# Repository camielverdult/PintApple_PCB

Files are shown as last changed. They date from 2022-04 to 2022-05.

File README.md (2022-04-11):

# PintApple PCB

This is version 2 of the PCB made for Project Integration in Applied Computer Science year 2 at Saxion Enschede.

## Features

| Function | Main part | Comments |
|---|---|---|
| MCU | [ESP32-S2-WROVER](https://www.espressif.com/sites/default/files/documentation/esp32-s2-wroom_esp32-s2-wroom-i_datasheet_en.pdf) | |
| Power | [XC6222B331MR-G](https://www.farnell.com/datasheets/3118383.pdf) | 3.3V, 700mA |
| Accelerometer | [MMA8652FCR1](https://www.farnell.com/datasheets/1869253.pdf) | |
| Display | [SSD1306 OLED](https://cdn-shop.adafruit.com/datasheets/SSD1306.pdf) | |
| Microphone | [MAX9814](https://www.adafruit.com/product/1713) | |
| SD card | [472192001](https://www.molex.com/molex/products/part-detail/memory_card_socket/0472192001) | |
| Heartbeat | [MAX30102](http://www.arduinoproducts.net/products/mh-et-live-max30102-heart-rate-sensor-module-puls-detection-blood-oxygen-concentration-test-for-arduino-ultra-low-power/) | |

## Renders

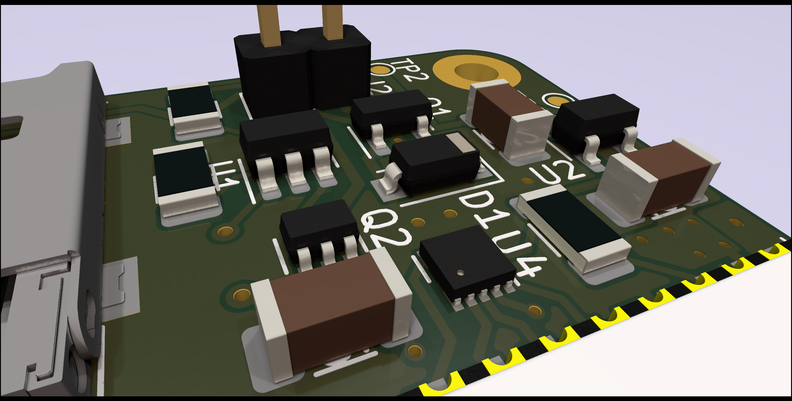
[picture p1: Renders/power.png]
Power circuitry


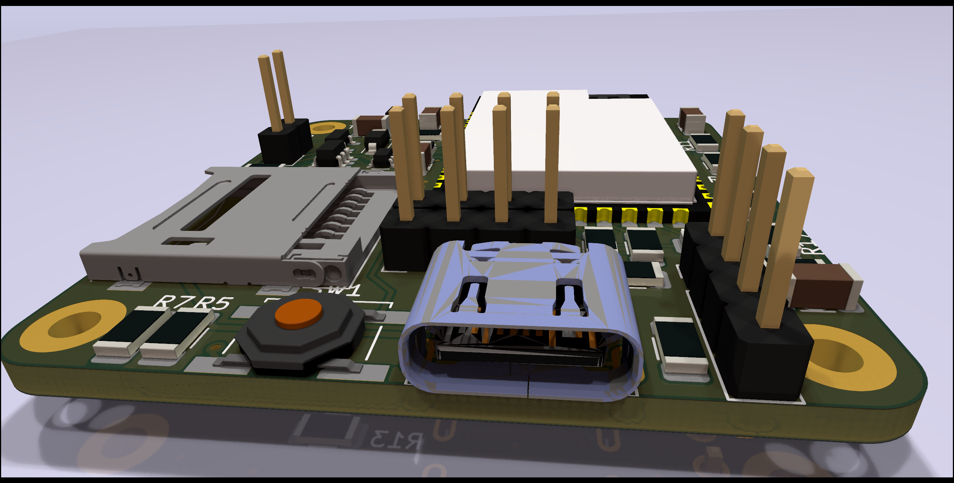
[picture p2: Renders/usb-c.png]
USB-C port


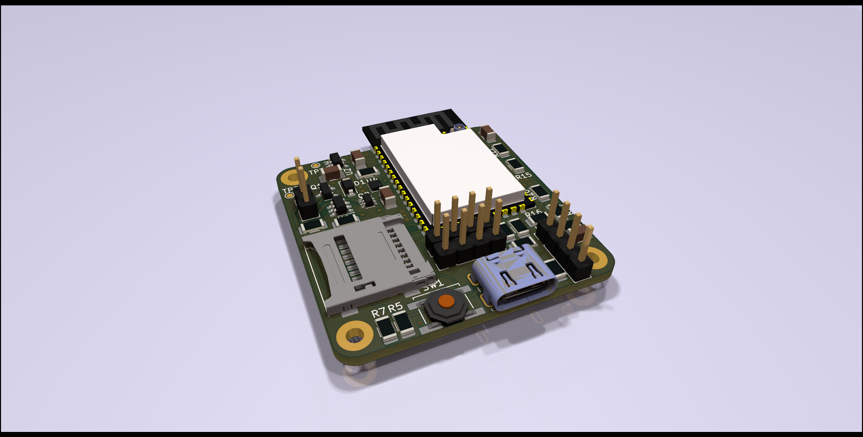
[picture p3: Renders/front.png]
Front side


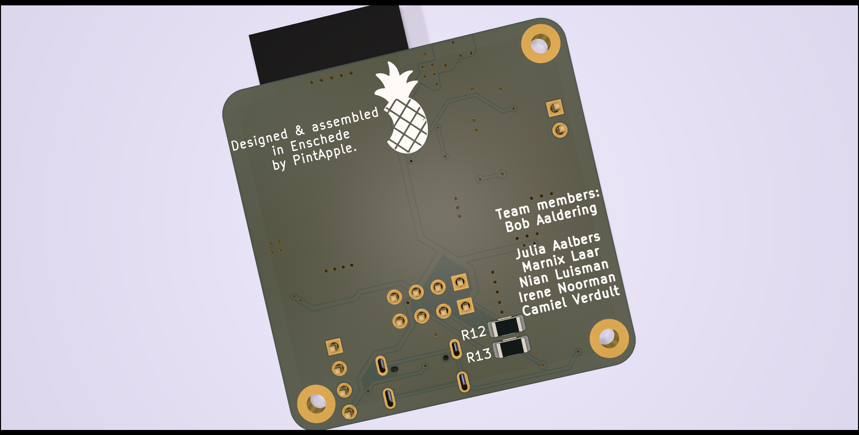
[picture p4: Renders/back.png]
Back side


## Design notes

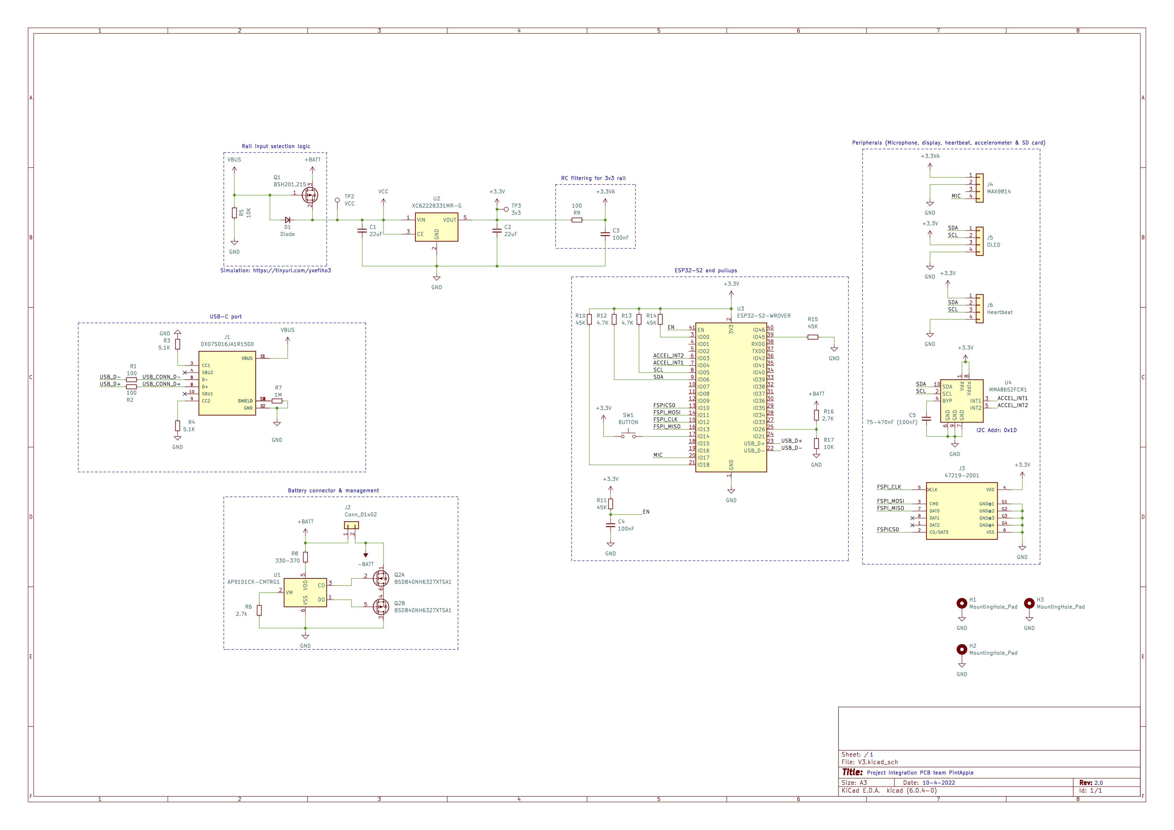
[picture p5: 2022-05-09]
Schematics/schematic_transparent.png

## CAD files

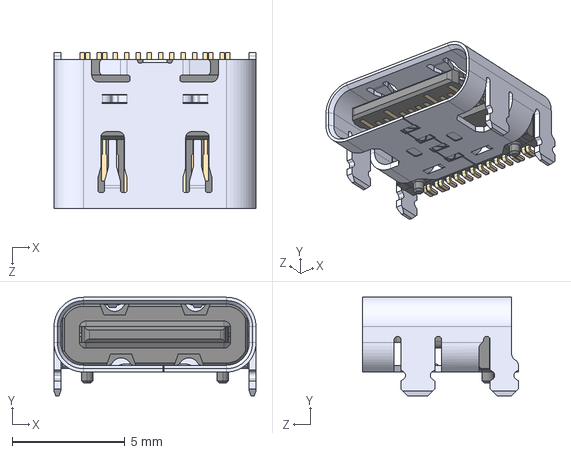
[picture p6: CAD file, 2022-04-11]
Project_3dmodels/DX07S016JA1R1500.STEP
8.94 x 4.36 x 6.90 mm

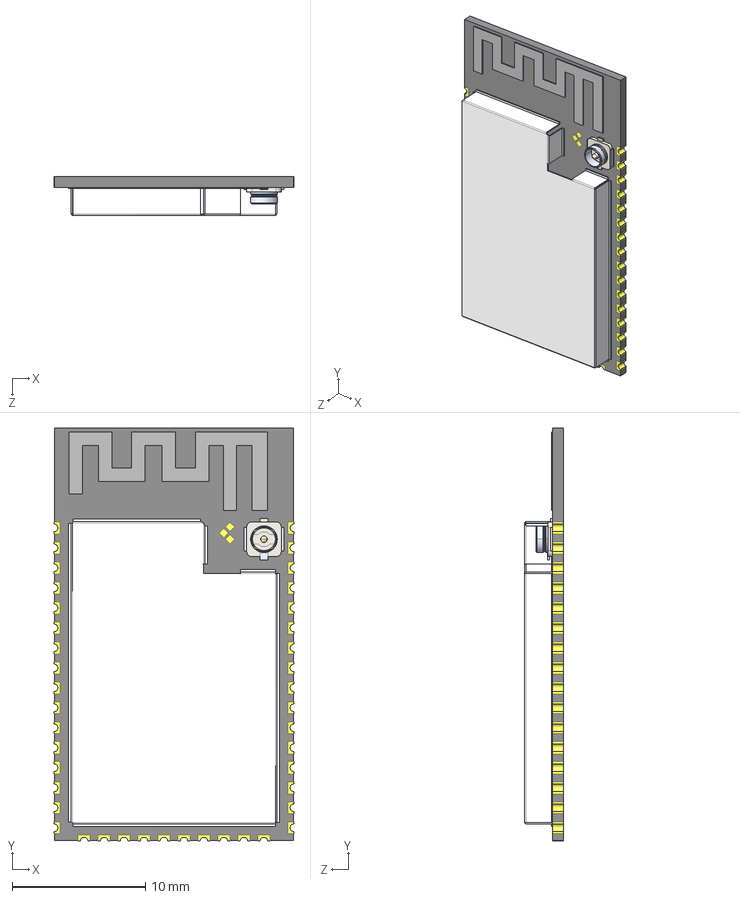
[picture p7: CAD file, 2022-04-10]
Project_3dmodels/ESP32-S2-WROVER.STEP
18.0 x 31.0 x 2.91 mm

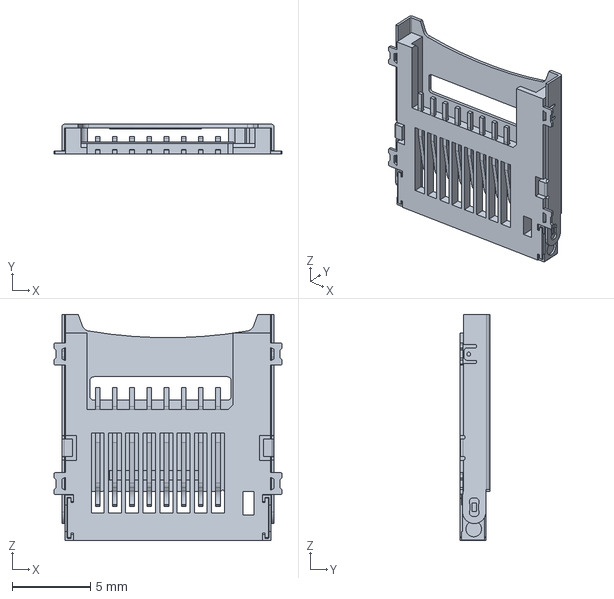
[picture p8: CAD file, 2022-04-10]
Project_3dmodels/472192001.stp
14.6 x 1.90 x 14.5 mm

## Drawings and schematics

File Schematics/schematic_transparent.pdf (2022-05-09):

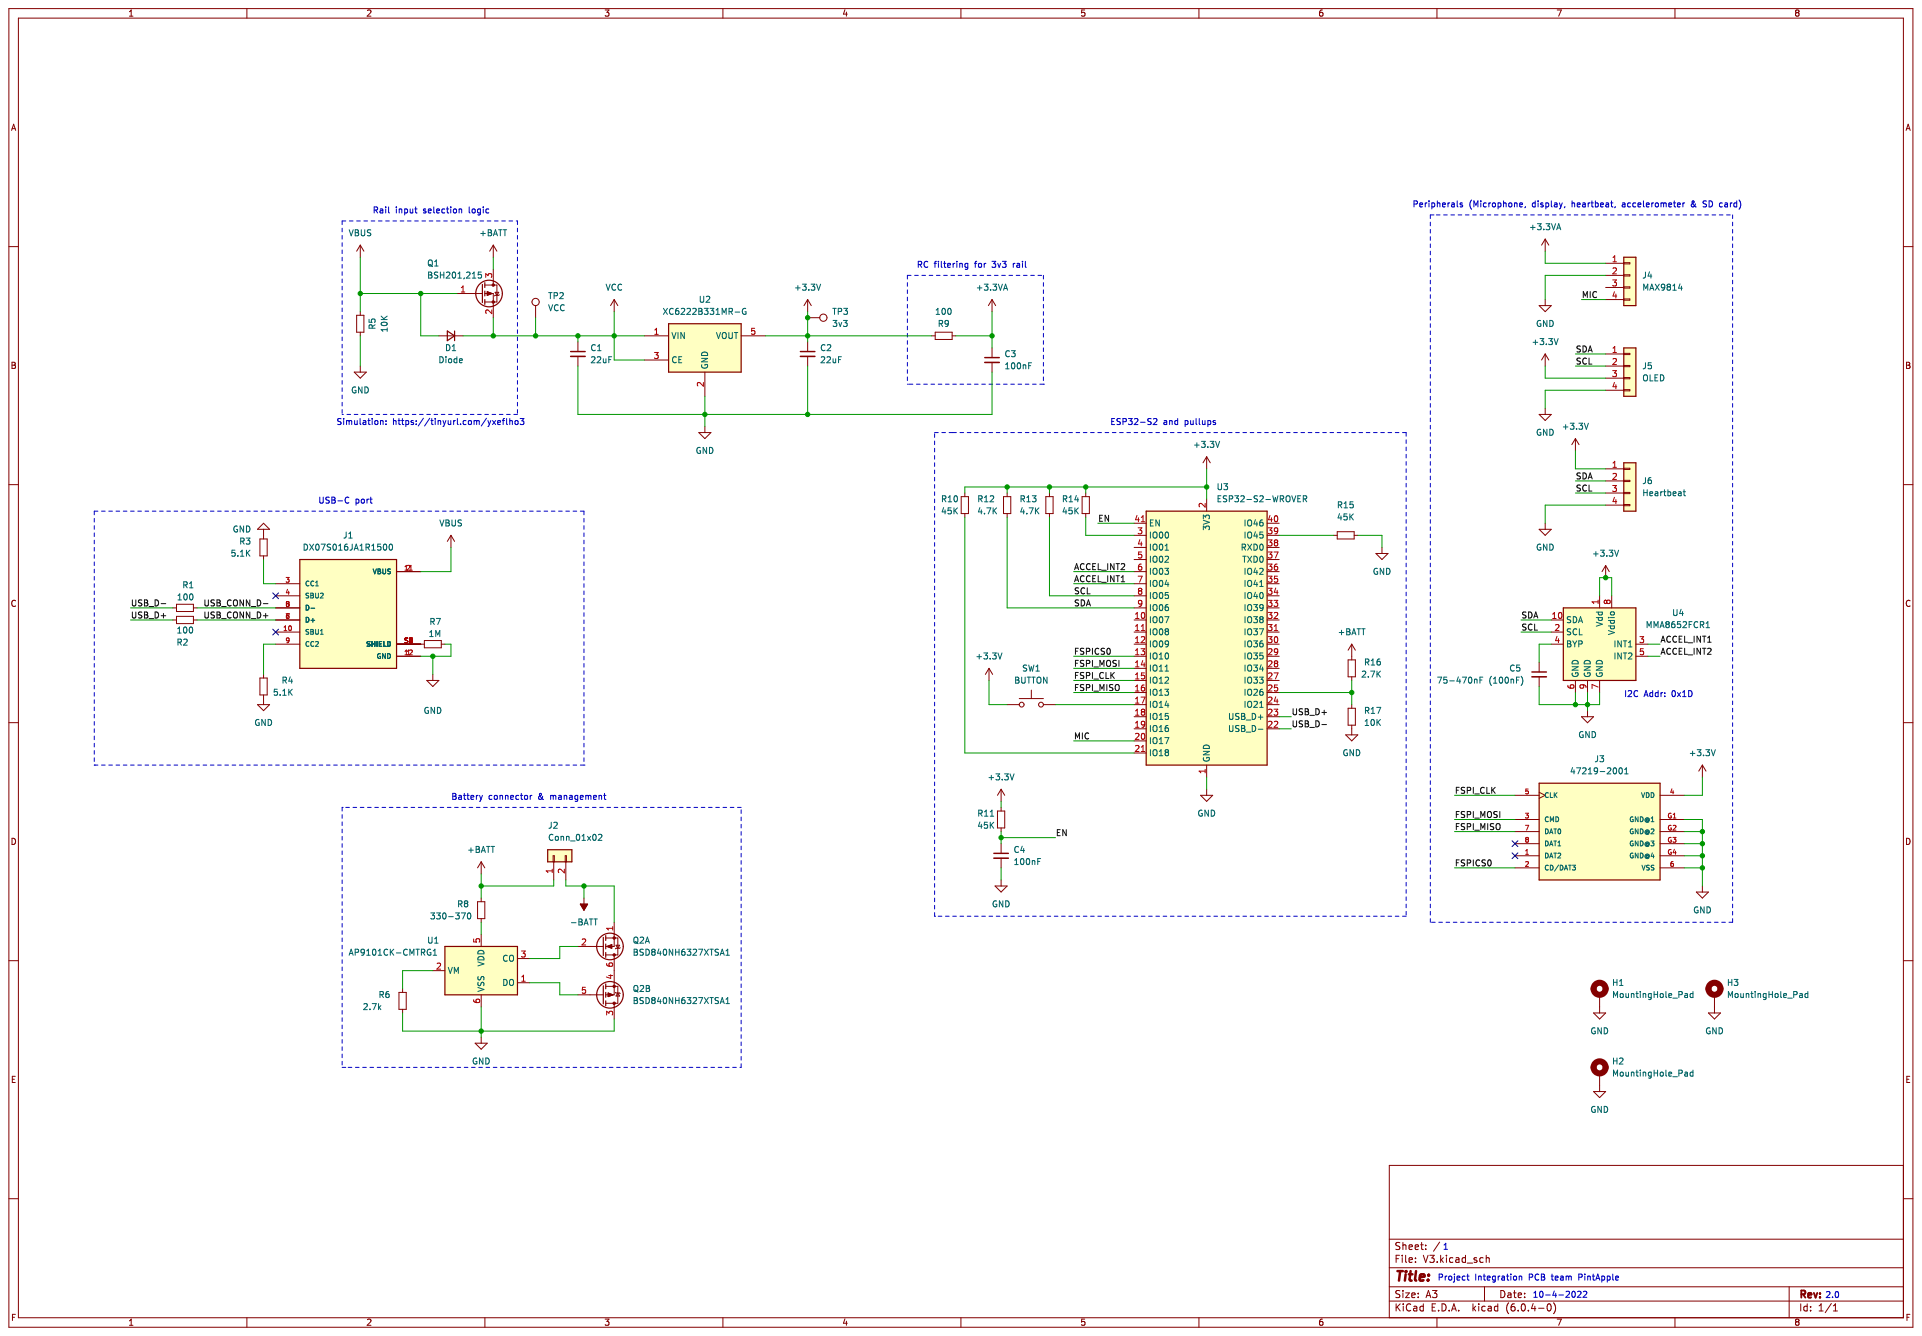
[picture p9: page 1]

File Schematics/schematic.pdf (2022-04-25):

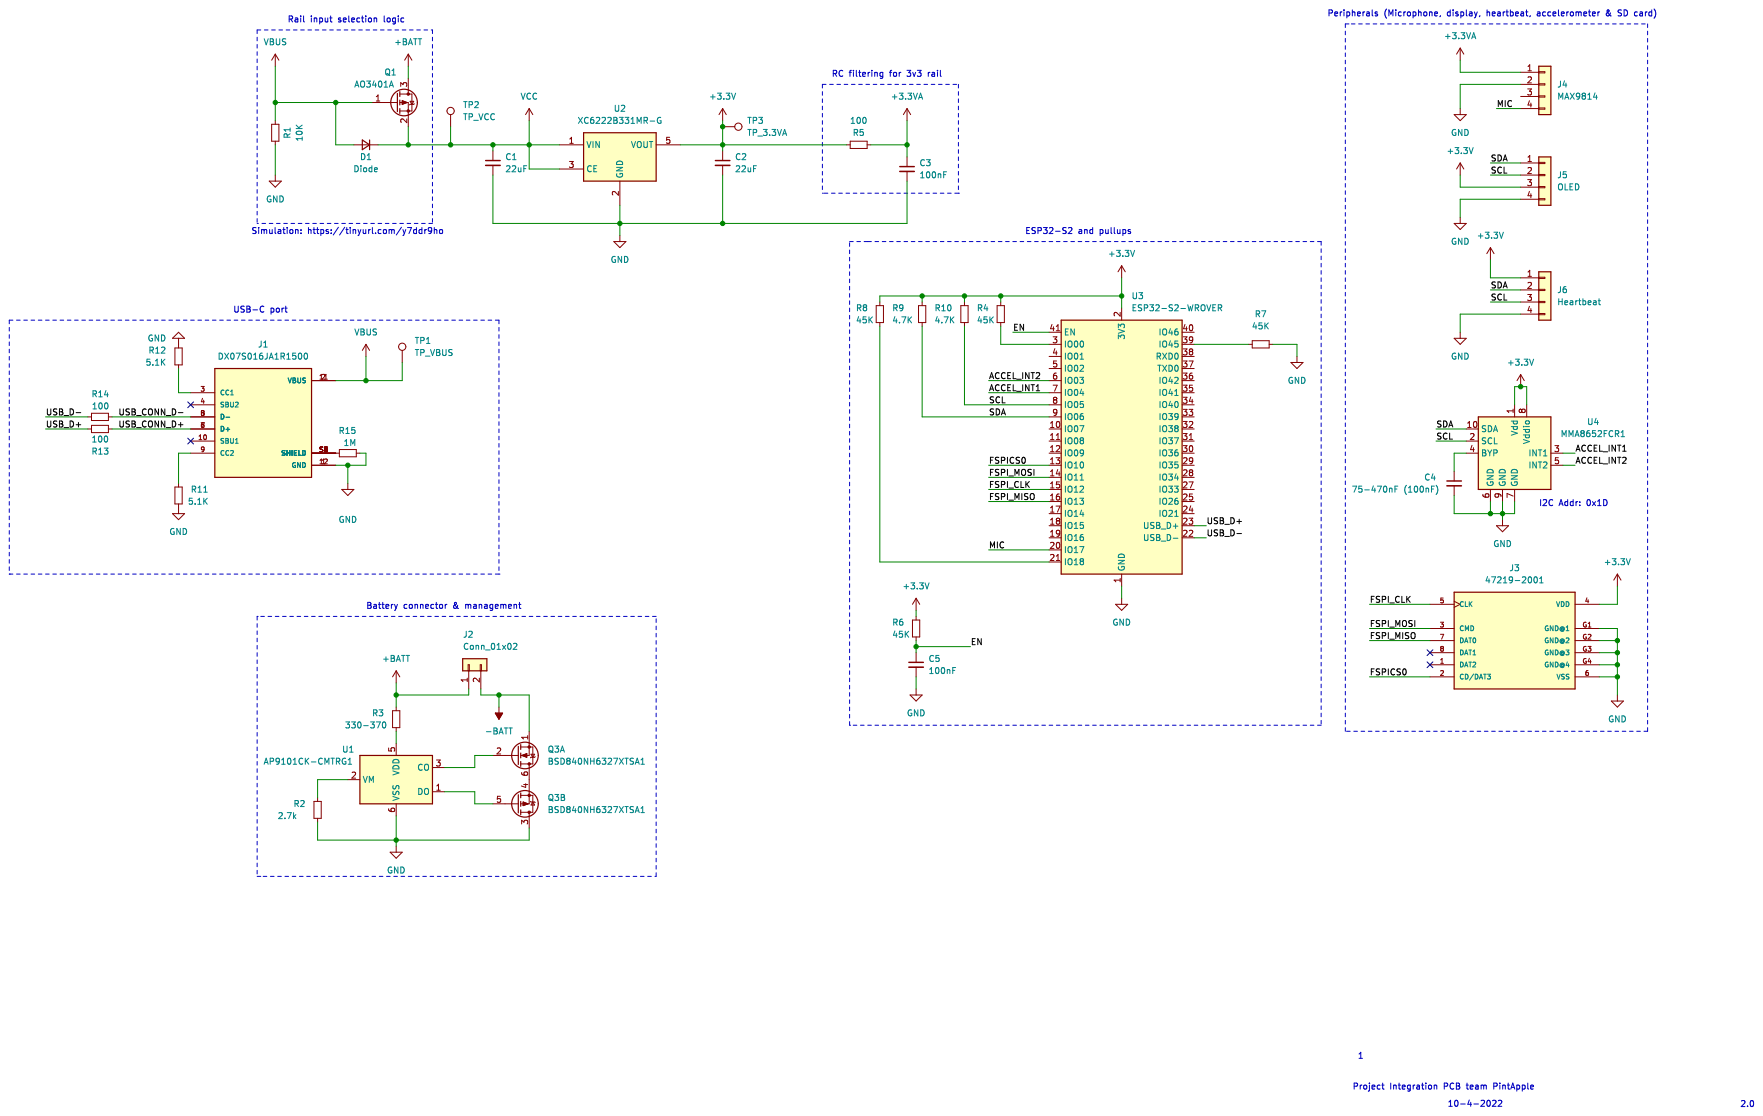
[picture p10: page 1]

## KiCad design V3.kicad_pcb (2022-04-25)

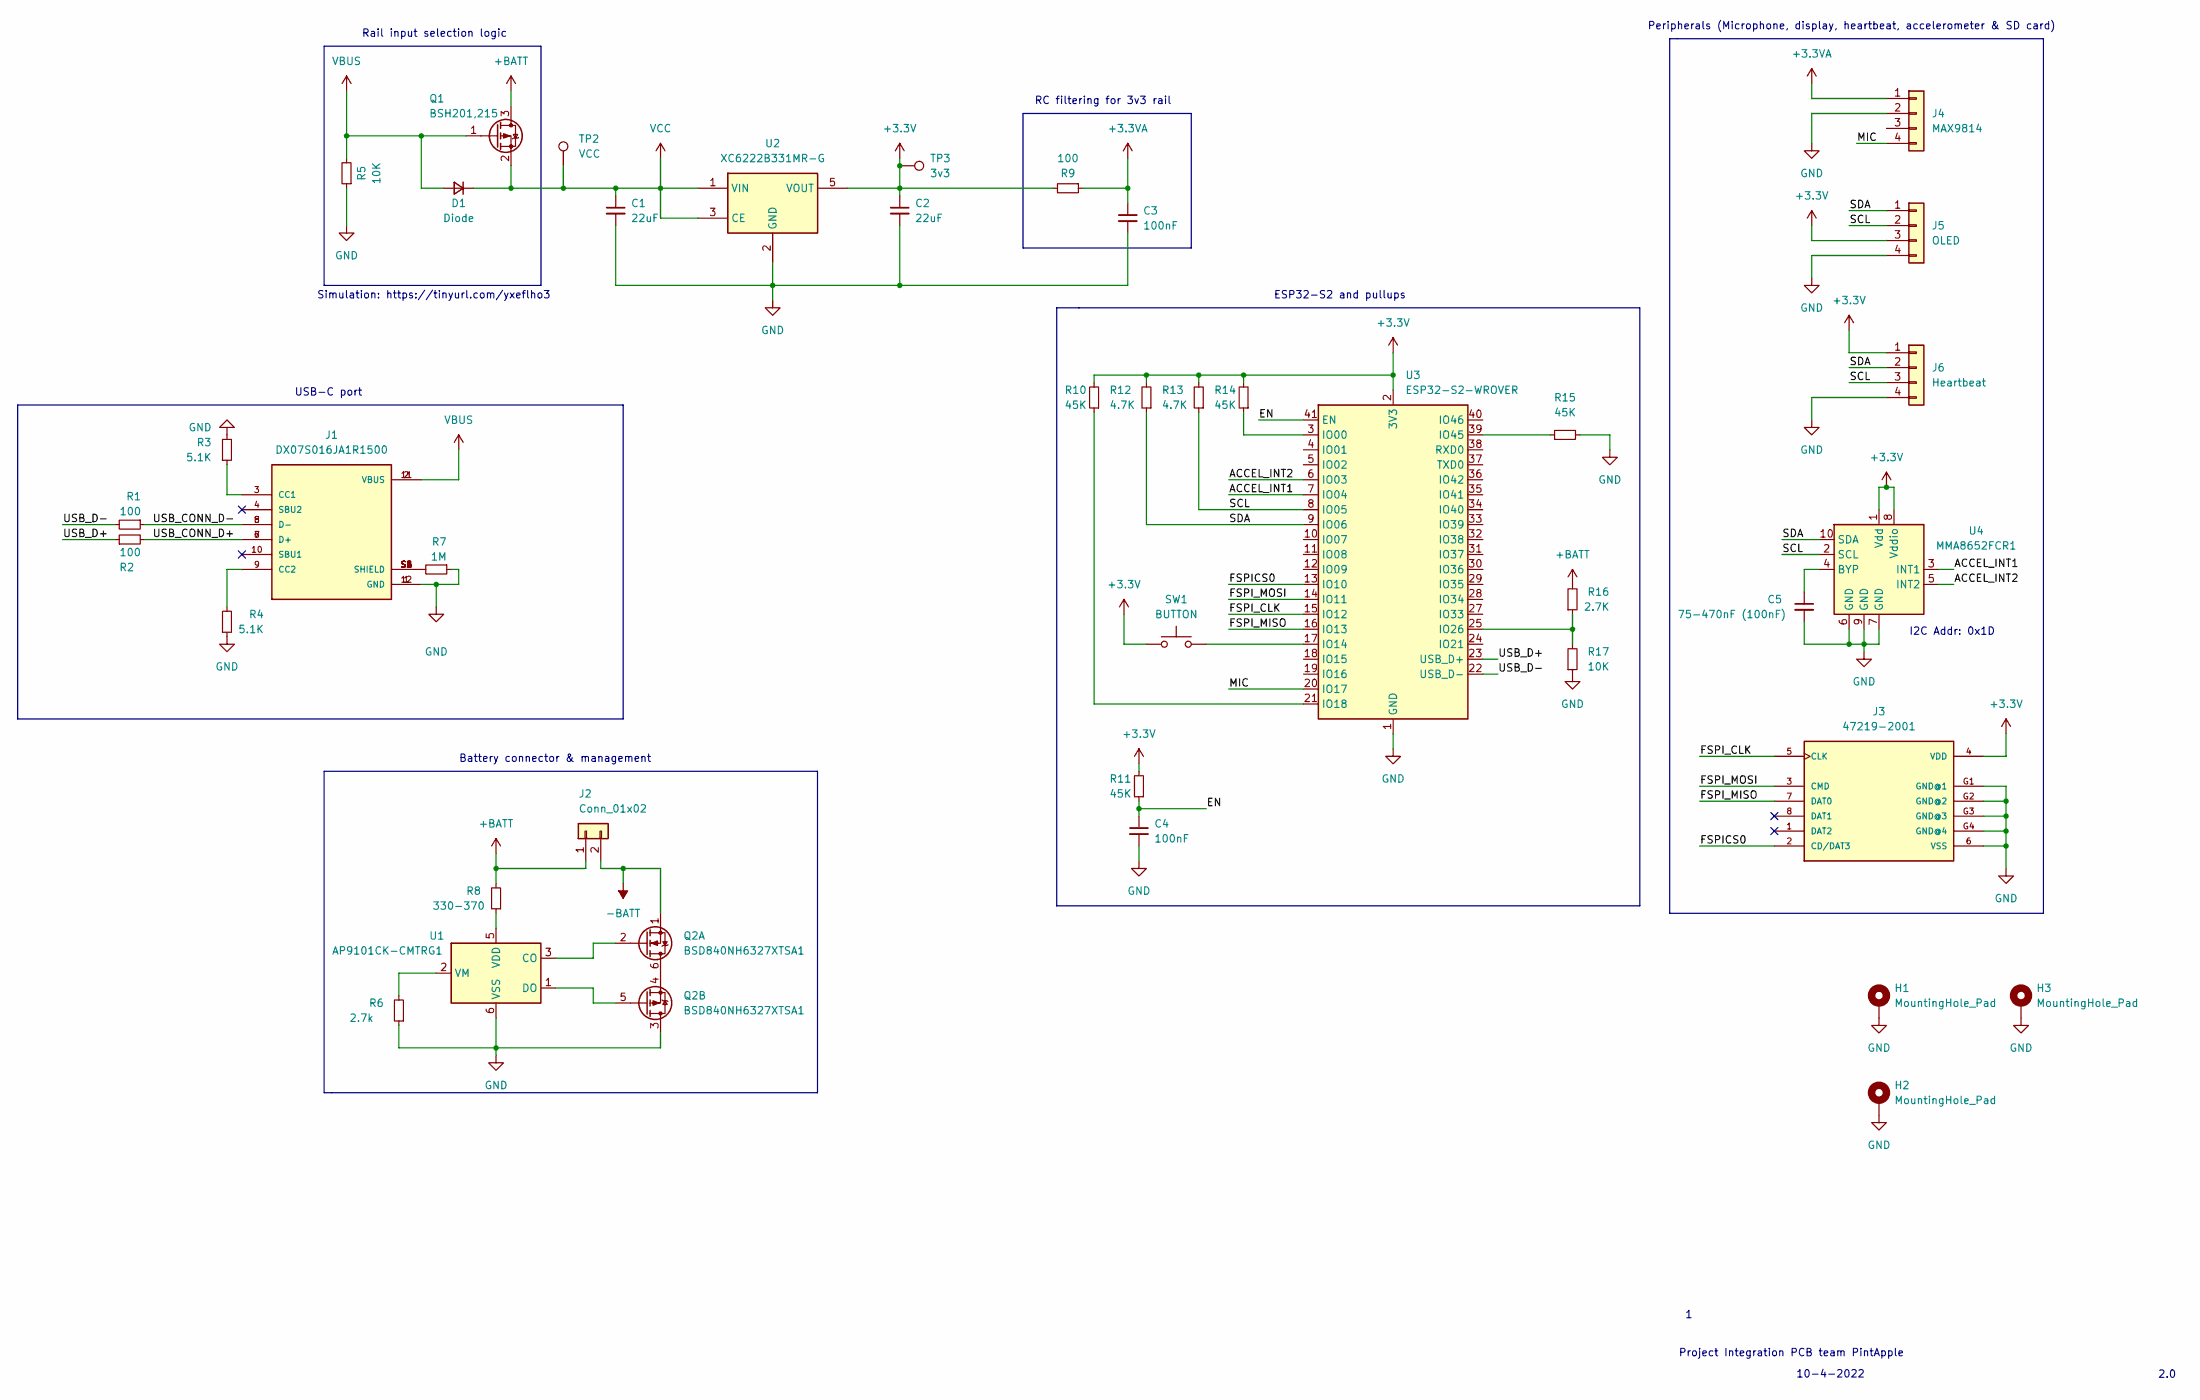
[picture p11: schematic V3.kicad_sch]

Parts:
C1, C2: 22uF; C_1206_3216Metric
C3, C4: 100nF; C_1206_3216Metric
C5: 75-470nF (100nF); C_1206_3216Metric
D1: Diode; D_SOD-123
H1, H2, H3: MountingHole_Pad; MountingHole_2.2mm_M2_Pad
J1: DX07S016JA1R1500; JAE_DX07S016JA1R1500; PARTREV 1
J2: Conn_01x02; PinHeader_1x02_P2.54mm_Vertical
J3: 47219-2001; MOLEX_47219-2001
J4: MAX9814; PinHeader_1x04_P2.54mm_Vertical
J5: OLED; PinHeader_1x04_P2.54mm_Vertical
J6: Heartbeat; PinHeader_1x04_P2.54mm_Vertical
Q1: BSH201,215; SOT-23
Q2: BSD840NH6327XTSA1; SOT-363_SC-70-6
R1, R2, R9: 100; R_1206_3216Metric
R3, R4: 5.1K; R_1206_3216Metric
R5, R17: 10K; R_1206_3216Metric
R6: 2.7k; R_1206_3216Metric
R7: 1M; R_1206_3216Metric
R8: 330-370; R_1206_3216Metric
R10, R11, R14, R15: 45K; R_1206_3216Metric
R12, R13: 4.7K; R_1206_3216Metric
R16: 2.7K; R_1206_3216Metric
SW1: BUTTON; SW_Push_1P1T_NO_CK_KSC6xxJ
TP2: VCC; TestPoint_Pad_D1.0mm
TP3: 3v3; TestPoint_Pad_D1.0mm
U1: AP9101CK-CMTRG1; SOT-23-6
U2: XC6222B331MR-G; SOT-23-5
U3: ESP32-S2-WROVER
U4: MMA8652FCR1; DFN-10_2x2mm_P0.4mm

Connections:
+3.3VA: C3.1, J4.1, R9.1
+3V3: C2.1, J3.4 (VDD), J5.3, J6.1, R9.2, R10.2, R11.2, R12.2, R13.2, R14.2, SW1.1, TP3.1, U2.5 (VOUT), U3.2 (3V3), U4.1 (Vdd), U4.8 (Vddio)
+BATT: J2.1, Q1.3 (D), R8.2, R16.2
-BATT: J2.2, Q2.1 (SN)
/ACCEL_INT1: U3.7 (IO04), U4.3 (INT1)
/ACCEL_INT2: U3.6 (IO03), U4.5 (INT2)
/EN: C4.1, R11.1, U3.41 (EN)
/FSPICS0: J3.2 (CD/DAT3), U3.13 (IO10)
/FSPI_CLK: J3.5 (CLK), U3.15 (IO12)
/FSPI_MISO: J3.7 (DAT0), U3.16 (IO13)
/FSPI_MOSI: J3.3 (CMD), U3.14 (IO11)
/MIC: J4.4, U3.20 (IO17)
/SCL: J5.2, J6.3, R13.1, U3.8 (IO05), U4.2 (SCL)
/SDA: J5.1, J6.2, R12.1, U3.9 (IO06), U4.10 (SDA)
/USB_CONN_D+: J1.6 (D+), J1.7 (D+), R2.2
/USB_CONN_D-: J1.5 (D-), J1.8 (D-), R1.1
/USB_D+: R2.1, U3.23 (USB_D+)
/USB_D-: R1.2, U3.22 (USB_D-)
GND: C1.2, C2.2, C3.2, C4.2, C5.2, H1.1, H2.1, H3.1, J1.1 (GND), J1.12 (GND), J3.6 (VSS), J3.G1 (GND@1), J3.G2 (GND@2), J3.G3 (GND@3), J3.G4 (GND@4), J4.2, J5.4, J6.4, Q2.3 (DP), R3.2, R4.1, R5.1, R6.1, R7.1, R15.2, R17.1, U1.6 (VSS), U2.2 (GND), U3.1 (GND), U3.26 (GND), U3.42 (GND), U3.43 (GND), U4.6 (GND), U4.7 (GND), U4.9 (GND)
unnamed: C5.1, U4.4 (BYP)
unnamed: J1.3 (CC1), R3.1
unnamed: J1.9 (CC2), R4.2
unnamed: J1.S1 (SHIELD), J1.S2 (SHIELD), J1.S3 (SHIELD), J1.S4 (SHIELD), J1.S5 (SHIELD), J1.S6 (SHIELD), R7.2
unnamed: Q2.2 (GN), U1.3 (CO)
unnamed: Q2.4 (SP), Q2.6 (DN)
unnamed: Q2.5 (GP), U1.1 (DO)
unnamed: R6.2, U1.2 (VM)
unnamed: R8.1, U1.5 (VDD)
unnamed: R10.1, U3.21 (IO18)
unnamed: R14.1, U3.3 (IO00)
unnamed: R15.1, U3.39 (IO45)
unnamed: R16.1, R17.2, U3.25 (IO26)
unnamed: SW1.2, U3.17 (IO14)
VBUS: D1.2 (A), J1.2 (VBUS), J1.11 (VBUS), Q1.1 (G), R5.2
VCC: C1.1, D1.1 (K), Q1.2 (S), TP2.1, U2.1 (VIN), U2.3 (CE)

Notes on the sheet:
I2C Addr: 0x1D
Battery connector & management
10-4-2022
Simulation: https://tinyurl.com/yxeflho3
USB-C port
ESP32-S2 and pullups
Project Integration PCB team PintApple
Peripherals (Microphone, display, heartbeat, accelerometer & SD card)
Rail input selection logic
RC filtering for 3v3 rail
2.0

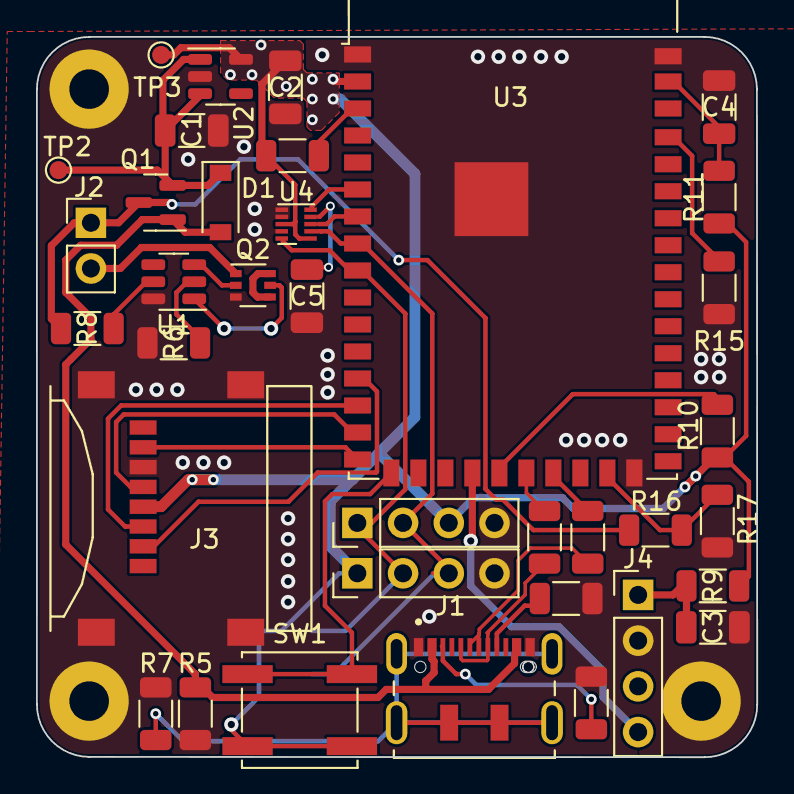
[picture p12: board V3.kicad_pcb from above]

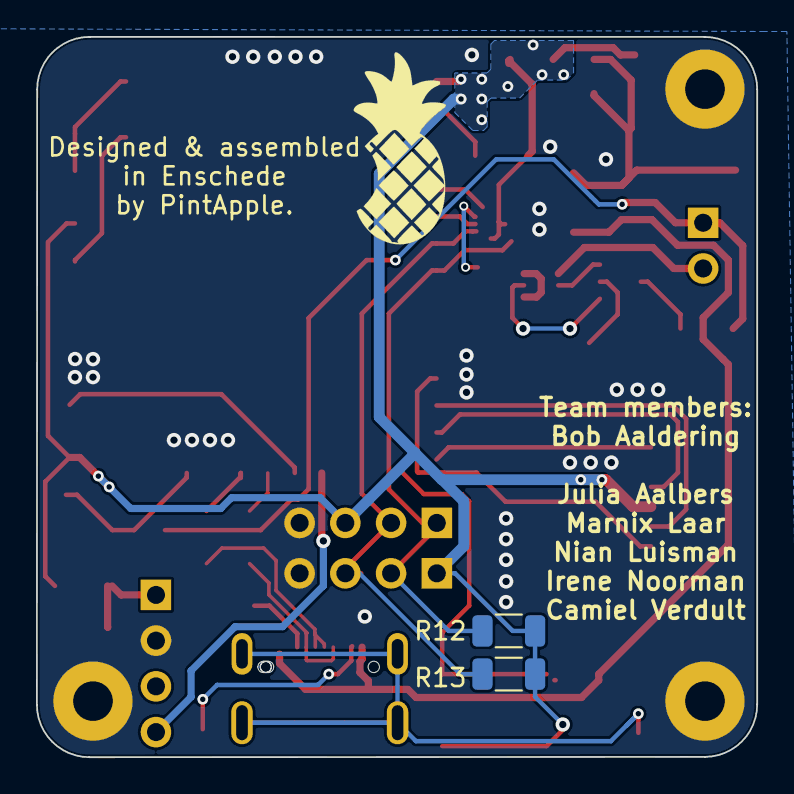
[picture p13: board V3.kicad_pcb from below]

Board: 2 copper layers, 40.0 x 40.0 mm, 41 parts (2 on the bottom side), 35 nets.

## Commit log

2022-04-09 Finalise schematic and start routing
    [V3.kicad_pcb, V3.kicad_sch]
2022-04-09 Route power
    [V3.kicad_pcb]
2022-04-10 Finish routing and export gerbers
    [V3-B_Cu.gbr, V3-B_Mask.gbr, V3-B_Paste.gbr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]
2022-04-10 Add 3d models, pcb & schematic touch up, graphics, update gerbers and add step file
    [472192001.stp, ESP32-S2-WROVER.STEP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]
2022-04-10 Switch out micro USB for USB-C
    [2137160001.stp, V3.kicad_pcb, V3.kicad_sch]
2022-04-11 Add USB-C port
    [DX07S016JA1R1500.STEP, V3.kicad_pcb, V3.kicad_sch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]
2022-04-11 Update gerbers
    [V3-B_Cu.gbr, V3-B_Mask.gbr, V3-B_Paste.gbr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]
2022-04-11 Add missing vias and update gerbers
    [V3-B_Cu.gbr, V3-B_Mask.gbr, V3-B_Paste.gbr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]

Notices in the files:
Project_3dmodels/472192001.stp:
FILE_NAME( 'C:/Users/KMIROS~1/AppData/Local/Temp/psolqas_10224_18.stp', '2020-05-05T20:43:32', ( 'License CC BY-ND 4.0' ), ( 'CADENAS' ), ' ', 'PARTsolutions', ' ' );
